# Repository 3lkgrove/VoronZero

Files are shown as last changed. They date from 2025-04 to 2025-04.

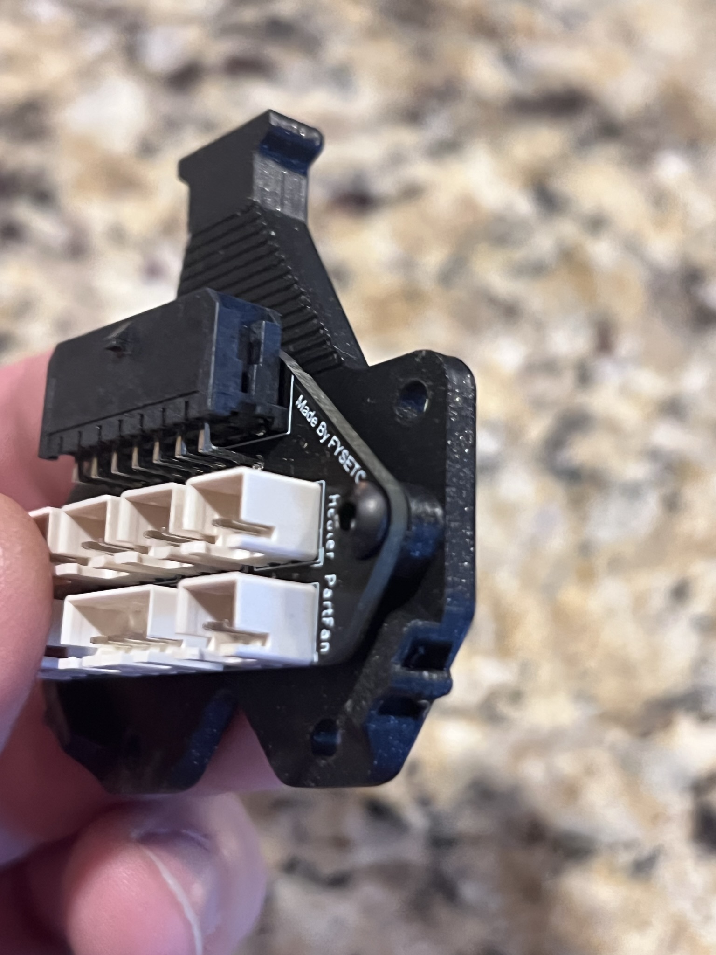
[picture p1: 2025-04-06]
STLs/Umbilical/V0.2/Images/2.JPEG

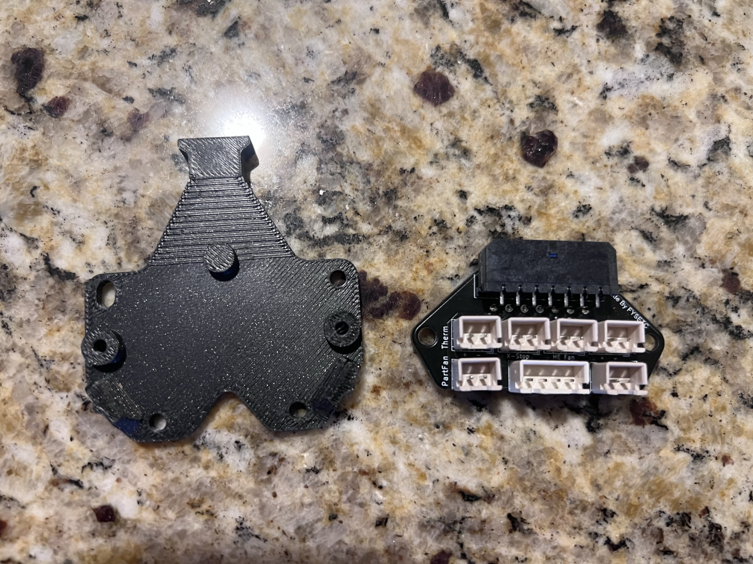
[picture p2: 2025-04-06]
STLs/Umbilical/V0.2/Images/1.JPEG

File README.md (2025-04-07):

# REPO for the Voron 0.2 kit from Formbot 3D

Here you will find some of the additional files, CAD and/or STL, for the components that are included in the Formbot kit of the Voron 0.2. I am also trying to include the manuals as I fidn them. I will also attempt to update a tracker and make some missing/incomplete manauals.

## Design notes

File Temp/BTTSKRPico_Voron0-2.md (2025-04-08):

```RUBY
[include mainsail.cfg]
# This file contains common pin mappings for the BIGTREETECH SKR Pico V1.0
# To use this config, the firmware should be compiled for the RP2040 with
# USB communication.

# The "make flash" command does not work on the SKR Pico V1.0. Instead,
# after running "make", copy the generated "out/klipper.uf2" file
# to the mass storage device in RP2040 boot mode

## Voron Design VORON 0.2 SKR Pico V1.0 config

## *** THINGS TO CHANGE/CHECK: ***
## MCU path                                                                     [mcu] section
## Z and Extruder motor currents                                                [tmc2209 stepper_*] sections. Uncomment the stepper motor you have
## Full steps per rotation for Extruder                                         [extruder] section
## Thermistor types                                                             [extruder] and [heater_bed] sections - See https://www.klipper3d.org/Config_Reference.html#common-thermistors for common thermistor types
## Motor currents                                                               [extruder] [stepper] and [_HOME_X/Y] macro sections
## PID tune                                                                     [extruder] and [heater_bed] sections
## Fine tune E steps                                                            [extruder] section
## For more info                                                                check https://docs.vorondesign.com/build/startup/#v0

[mcu]
#####################################################################
# Obtain definition by "ls -l /dev/serial/by-id/"
#####################################################################
serial: /dev/serial/by-id/usb-Klipper_rp2040_REPLACE_WITH_YOUR_VALUE
## serial: /dev/ttyAMA0 											# for UART connection
restart_method: command

[temperature_sensor mcu_temp]
sensor_type: temperature_mcu
min_temp: 0
max_temp: 100

[temperature_sensor raspberry_pi]
sensor_type: temperature_host
min_temp: 10
max_temp: 100

[printer]
kinematics: corexy
max_velocity: 200
max_accel: 2000
max_z_velocity: 15
max_z_accel: 300
square_corner_velocity: 6.0

#####################################################################
#      X/Y Stepper Settings
#####################################################################

[stepper_x]
step_pin: gpio11
## Refer to https://docs.vorondesign.com/build/startup/#v0
dir_pin: gpio10                                                     # Check motor direction in link above. If inverted, add a ! before gpio10
enable_pin: !gpio12
rotation_distance: 40
microsteps: 32
full_steps_per_rotation: 200                                        # Set to 400 for 0.9° degree stepper motor, 200 is for 1.8° stepper motors
endstop_pin: tmc2209_stepper_x:virtual_endstop
position_endstop: 120
position_max: 120
homing_speed: 40
homing_retract_dist: 0
homing_positive_dir: true

[tmc2209 stepper_x]
uart_pin: gpio9
tx_pin: gpio8
uart_address: 0
interpolate: False
# run_current: 0.0            
# you need to calculate the run_current value using the equation (rated_motor_current * 0.707 = Maximum_run_current) start with a value that is about 60%-70% of your maximum value.
sense_resistor: 0.110
stealthchop_threshold: 0                                            # Set to 999999 to turn stealthchop on, and 0 to use spreadcycle
diag_pin: ^gpio4    												# YOU NEED TO JUMP THIS DIAG PIN ON YOUR BOARD FOR SENSORLESS HOMING TO WORK 
driver_SGTHRS: 255  												# this is set to 255 which is the MAX sensitivity for sensorless homing, you will need to tune this later

[stepper_y]
step_pin: gpio6
## Refer to https://docs.vorondesign.com/build/startup/#v0
dir_pin: gpio5                                                      # Check motor direction in link above. If inverted, add a ! before gpio5
enable_pin: !gpio7
rotation_distance: 40
microsteps: 32
full_steps_per_rotation: 200                                        # Set to 400 for 0.9° degree stepper motor, 200 is for 1.8° stepper motors
endstop_pin: tmc2209_stepper_y:virtual_endstop
position_endstop: 120
position_max: 120
homing_speed: 40
homing_retract_dist: 0
homing_positive_dir: true

[tmc2209 stepper_y]
uart_pin: gpio9
tx_pin: gpio8
uart_address: 2
interpolate: False
# run_current: 0.0            
# you need to calculate the run_current value using the equation (rated_motor_current * 0.707 = Maximum_run_current) start with a value that is about 60%-70% of your maximum value.
sense_resistor: 0.110
stealthchop_threshold: 0                                            # Set to 999999 to turn stealthchop on, and 0 to use spreadcycle
diag_pin: ^gpio3    												# YOU NEED TO JUMP THIS DIAG PIN ON YOUR BOARD FOR SENSORLESS HOMING TO WORK 
driver_SGTHRS: 255  												# this is set to 255 which is the MAX sensitivity for sensorless homing, you will need to tune this later

#####################################################################
#   Z Stepper Settings
#####################################################################

[stepper_z]
step_pin: gpio19
dir_pin: !gpio28                                                    # Remove the ! before gpio28 if motor direction is inverted.
enable_pin: !gpio2
rotation_distance: 8                                                # For T8x8 integrated lead screw
microsteps: 32
endstop_pin: ^gpio25
position_endstop: 120
position_max: 120
position_min: -1.5
homing_speed: 20
second_homing_speed: 3.0
homing_retract_dist: 3.0

[tmc2209 stepper_z]
uart_pin: gpio9
tx_pin: gpio8
uart_address: 1
interpolate: False
## For OMC (StepperOnline) 17LS13-0404E-200G 0.4A 
#run_current: 0.2
## For LDO-42STH25-1004CL200E 1.0A
#run_current: 0.37
sense_resistor: 0.110
stealthchop_threshold: 0                                            # Set to 999999 to turn stealthchop on, and 0 to use spreadcycle

#####################################################################
#   Extruder
#####################################################################

[extruder]
step_pin: gpio14
dir_pin: gpio13                                                     # Add ! if moving opposite direction
enable_pin: !gpio15
#full_steps_per_rotation: 200                                       # Set to 200 for LDO 1.8° stepper motor, and set to 400 for OMC(StepperOnline) 0.9° stepper motor
rotation_distance: 22.23                                            # See calibrating rotation_distance on extruders doc
gear_ratio: 50:10                                                   # For Mini Afterburner
microsteps: 32
nozzle_diameter: 0.400
filament_diameter: 1.750
heater_pin: gpio23
## Check what thermistor type you have. See https://www.klipper3d.org/Config_Reference.html#common-thermistors for common thermistor types.
## Use "Generic 3950" for NTC 100k 3950 thermistors
#sensor_type:
sensor_pin: gpio27
control: pid                                                        # Do PID calibration after initial checks
pid_Kp: 28.182
pid_Ki: 1.978
pid_Kd: 100.397
min_temp: 0
max_temp: 270
min_extrude_temp: 170
max_extrude_only_distance: 150
max_extrude_cross_section: 0.8
pressure_advance: 0.0                                               # See tuning pressure advance doc
pressure_advance_smooth_time: 0.040

[tmc2209 extruder]
uart_pin: gpio9
tx_pin: gpio8
uart_address: 3
interpolate: False
## For OMC (StepperOnline) 14HR07-1004VRN 1A 0.9°
#run_current: 0.5 # for OMC 14HR07-1004VRN rated at 1A
## For LDO LDO 36STH17-1004AHG 1A 1.8° 
#run_current: 0.3 # for LDO 36STH17-1004AHG
## For LDO LDO 36STH20-1004AHG 1A 1.8° 
#run_current: 0.6 # for LDO 36STH20-1004AHG
sense_resistor: 0.110
stealthchop_threshold: 0                                            # Set to 0 for spreadcycle, avoid using stealthchop on extruder

#####################################################################
#   Bed Heater
#####################################################################

[heater_bed]
heater_pin: gpio21
## Check what thermistor type you have. See https://www.klipper3d.org/Config_Reference.html#common-thermistors for common thermistor types.
## Use "Generic 3950" for Keenovo heaters
#sensor_type:
sensor_pin: gpio26
smooth_time: 3.0
#max_power: 0.6                                                     # Only needed for 100w pads
min_temp: 0
max_temp: 120
control: pid                                                        # Do PID calibration after initial checks
pid_kp: 68.453
pid_ki: 2.749
pid_kd: 426.122

#####################################################################
# Fan Control
#####################################################################

[heater_fan hotend_fan]
pin: gpio18
max_power: 1.0
kick_start_time: 0.5
heater: extruder
heater_temp: 50.0
#fan_speed: 1.0                                                     # You can't PWM the delta fan unless using blue wire

[fan]
pin: gpio17
max_power: 1.0
kick_start_time: 0.5                                                # Depending on your fan, you may need to increase this value if your fan will not start
off_below: 0.13
cycle_time: 0.010

[controller_fan MCU_fan]
pin: gpio20
max_power: 1.0
kick_start_time: 0.5
heater: extruder
#fan_speed: 1.0 

#####################################################################
#   Filament Runout Sensor
#####################################################################

#[filament_switch_sensor Filament_Runout_Sensor]
#pause_on_runout: True
#runout_gcode: PAUSE
#switch_pin: gpio16

#####################################################################
# Homing and Gantry Adjustment Routines
#####################################################################

[idle_timeout]
timeout: 1800

#[safe_z_home]
##home_xy_position: 120,120 										# these coordinates must NOT be greater than the values specified in "position_max:" for the X and Y steppers
#speed: 50.0
#z_hop: 5

## To be used with BED_SCREWS_ADJUST
[bed_screws]
screw1: 60,5
screw1_name: front screw
screw2: 5,115
screw2_name: back left
screw3: 115,115
screw3_name: back right

#####################################################################
# Neopixel
#####################################################################

[neopixel board_rgb]
pin: gpio24
chain_count: 1
color_order: GRB
initial_RED: 0.0
initial_GREEN: 0.1
initial_BLUE: 0.0

#####################################################################
#   V0 Display
#####################################################################
# [mcu display]
# serial: **PASTE YOUR SERIAL PORT HERE AND UNCOMMENT**
# restart_method: command

# [display]
# lcd_type: sh1106
# i2c_mcu: display
# i2c_bus: i2c1a
# # Set the direction of the encoder wheel
# #   Standard: Right (clockwise) scrolls down or increases values. Left (counter-clockwise scrolls up or decreases values.
# encoder_pins: ^display:PA3, ^display:PA4
# #   Reversed: Right (clockwise) scrolls up or decreases values. Left (counter-clockwise scrolls down or increases values.
# #encoder_pins: ^display:PA4, ^display:PA3
# click_pin: ^!display:PA1
# kill_pin: ^!display:PA5
# #x_offset: 2
# #   Use X offset to shift the display towards the right. Value can be 0 to 3
# #vcomh: 0
# #   Set the Vcomh value on SSD1306/SH1106 displays. This value is
# #   associated with a "smearing" effect on some OLED displays. The
# #   value may range from 0 to 63. Default is 0.
# #   Adjust this value if you get some vertical stripes on your display. (31 seems to be a good value)

# [neopixel displayStatus]
# pin: display:PA0
# chain_count: 1
# color_order: GRB
# initial_RED: 0.2
# initial_GREEN: 0.05
# initial_BLUE: 0

```

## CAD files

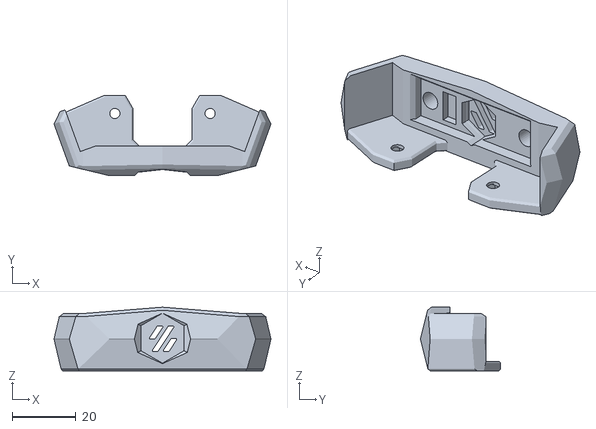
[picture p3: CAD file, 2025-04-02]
STLs/Kirigami/Stealth_Bed_Main_Body.stl
68.2 x 25.2 x 20.0

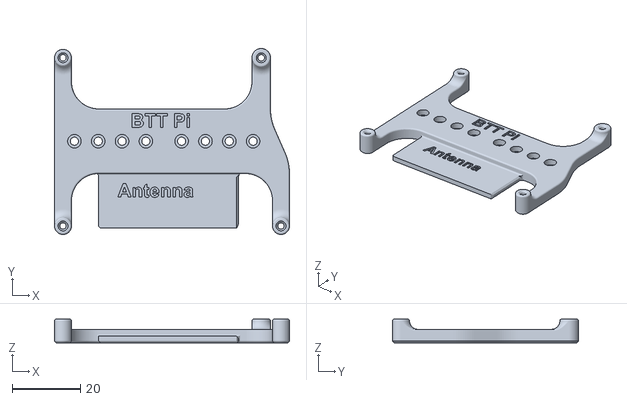
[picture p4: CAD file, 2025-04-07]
STLs/btt_pi_mount_antenna.stl
69.0 x 54.6 x 7.00

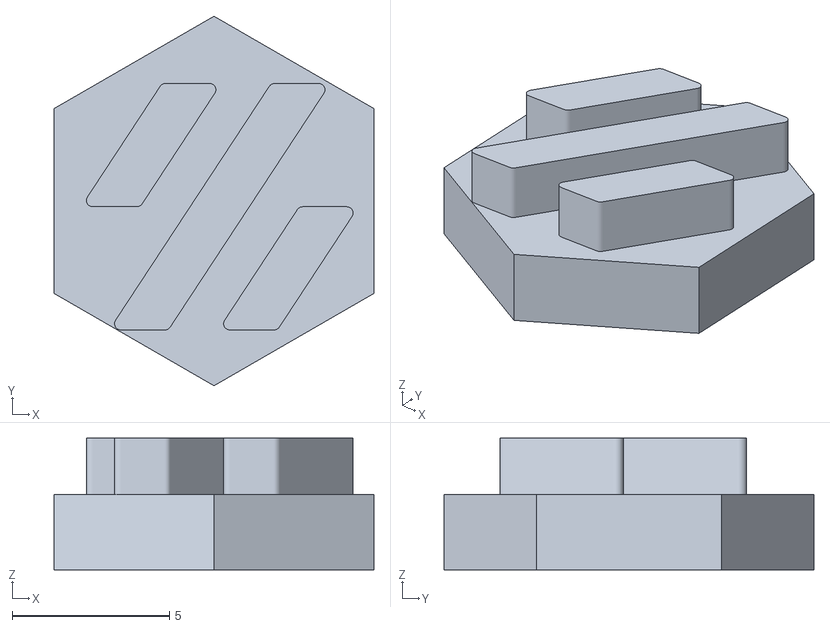
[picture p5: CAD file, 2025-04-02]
STLs/Kirigami/[c]_Stealth_Bed_Diffuser.stl
10.2 x 11.8 x 4.20

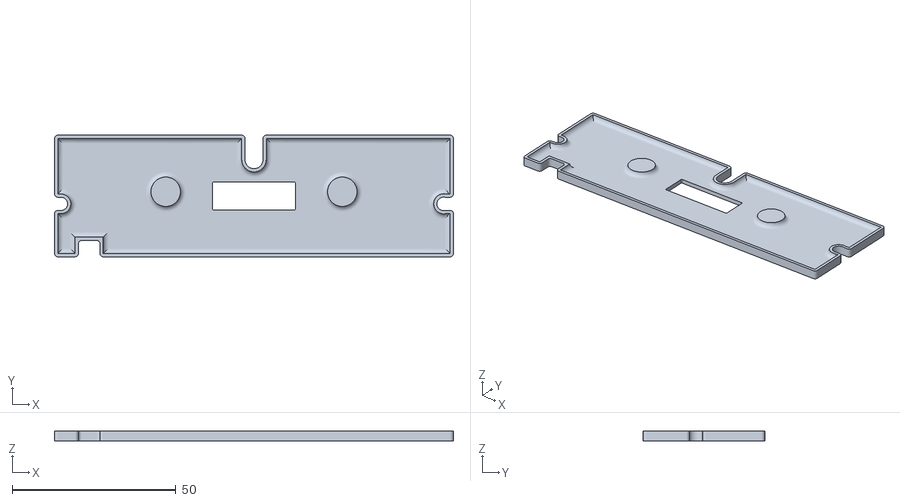
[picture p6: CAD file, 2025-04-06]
STLs/Umbilical/Multicolor PCB Cover/PCB_Cover_Voron.stl
122.0 x 37.2 x 3.00

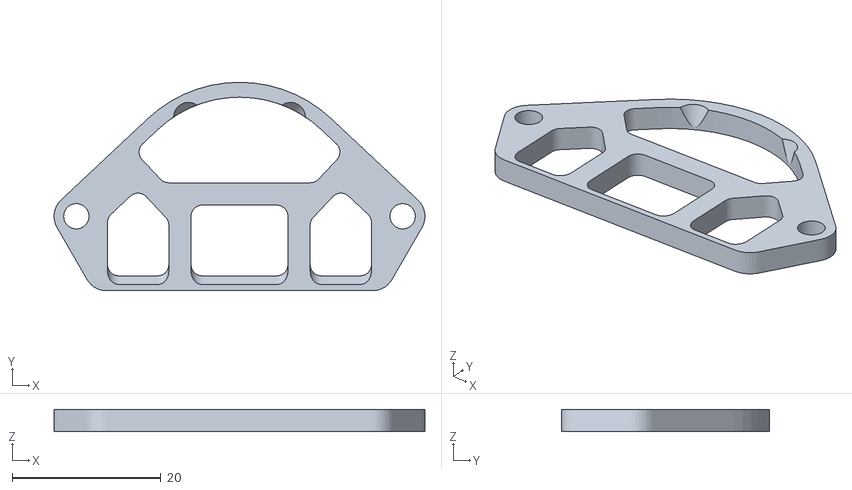
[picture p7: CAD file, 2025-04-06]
STLs/Umbilical/ToolheadSpacer.STL
49.8 x 28.0 x 3.00

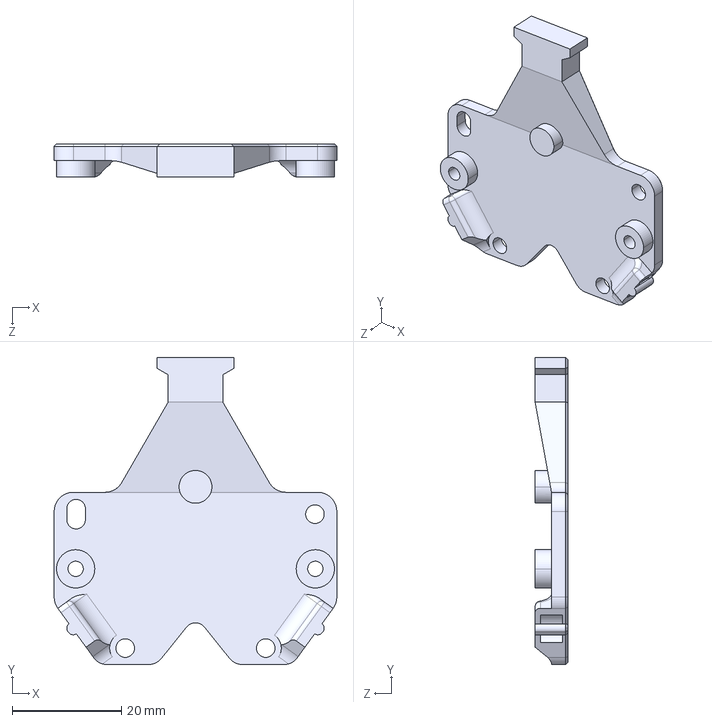
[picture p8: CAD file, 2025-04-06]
STLs/Umbilical/V0.2/V0.2_Toolhead_PCB_Mount.STEP
51.7 x 56.2 x 6.00 mm

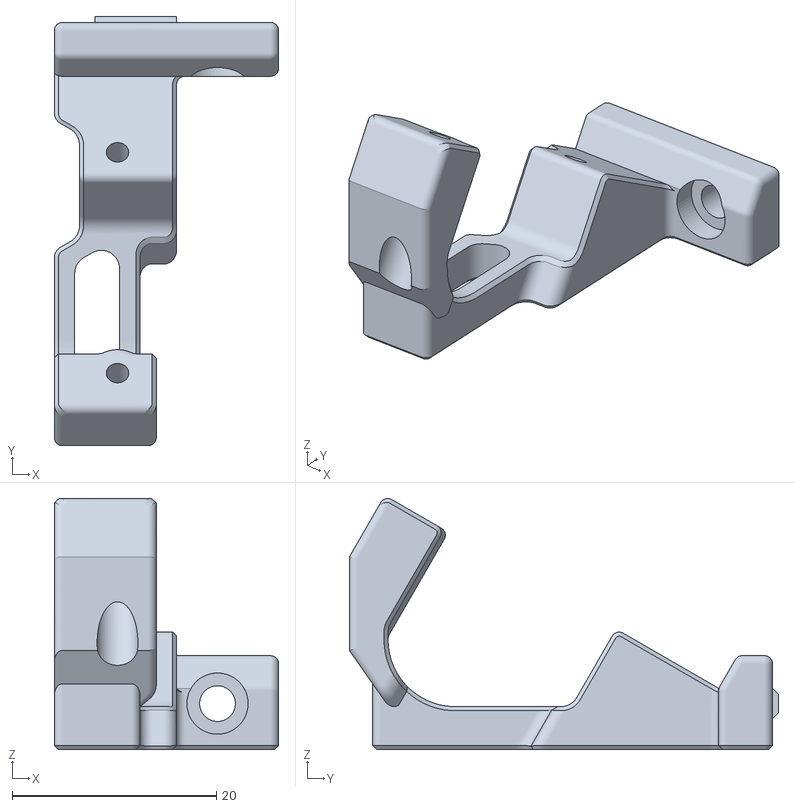
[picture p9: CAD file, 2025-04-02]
STLs/V0/Display/Display_Mount_Left_x1.stl
22.0 x 42.1 x 24.6

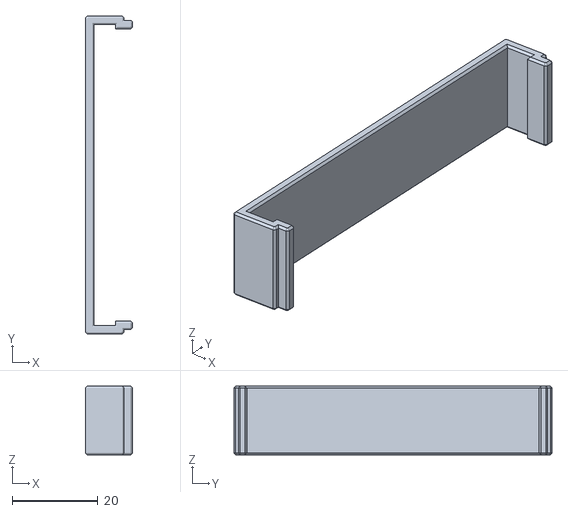
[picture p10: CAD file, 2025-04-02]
STLs/V0/Electronics/PSU_Cover_x1.STL
11.0 x 74.2 x 16.0

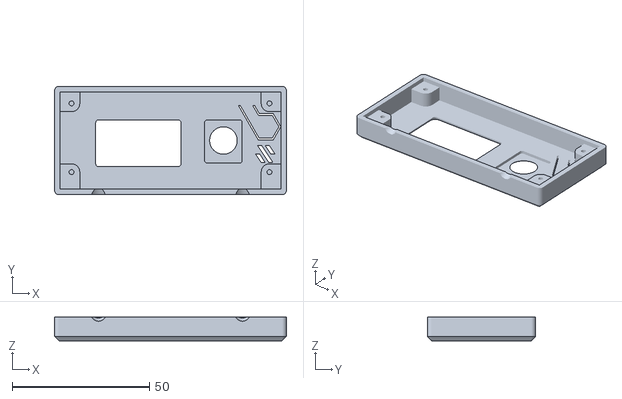
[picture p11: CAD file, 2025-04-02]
STLs/V0/Multibody_STLs/Display/Display_Faceplate_Multibody_x1.stl
84.4 x 39.4 x 8.63

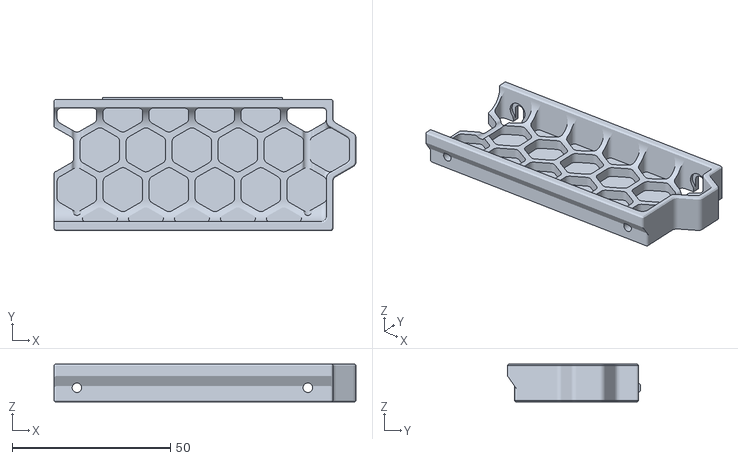
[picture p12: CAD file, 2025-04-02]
STLs/V0/Multibody_STLs/Skirts/Side_Skirt_Mirror_Multibody_x2.stl
95.5 x 42.1 x 12.0

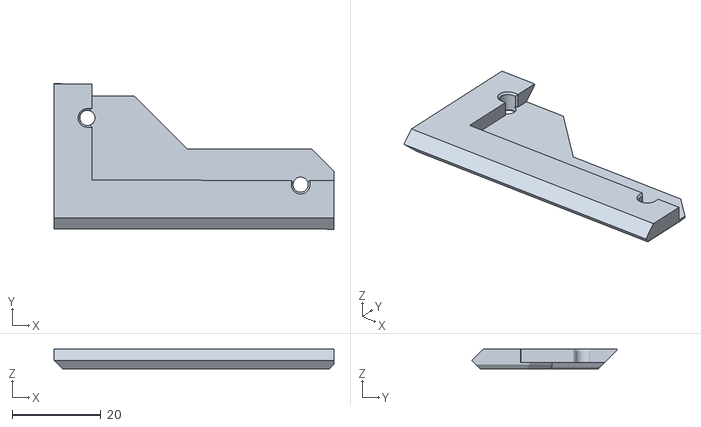
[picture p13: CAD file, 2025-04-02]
STLs/V0/Panel_Mounting/Right_Top_Rear_Panel_Clip_x1.stl
63.0 x 32.7 x 4.40

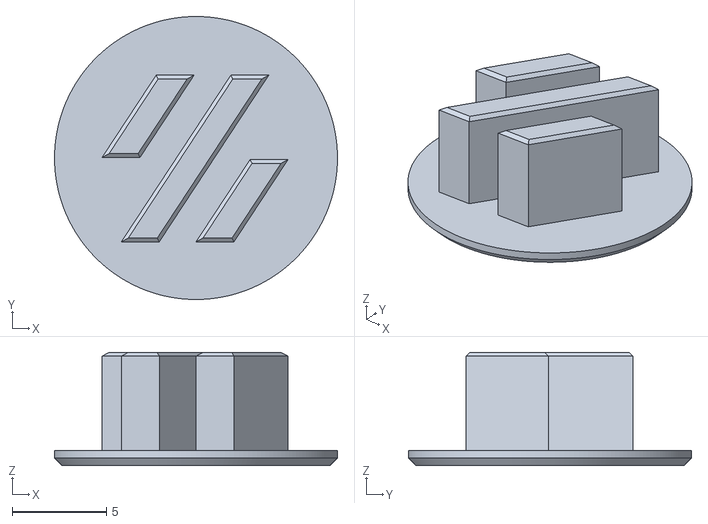
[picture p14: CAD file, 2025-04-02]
STLs/V0/Skirts/[a]_Logo_Insert_x2.stl
15.0 x 15.0 x 6.00

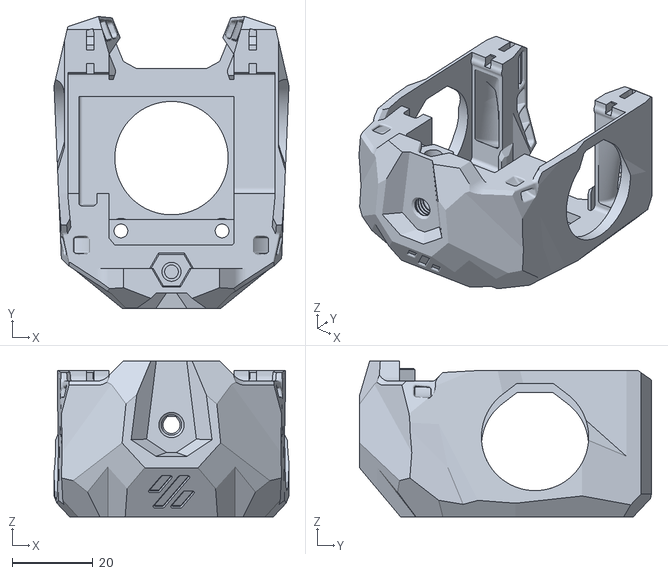
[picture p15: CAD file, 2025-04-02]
STLs/V0/Toolheads/Bowden/MiniSB_Bowden_M6.STL
58.1 x 72.2 x 38.5

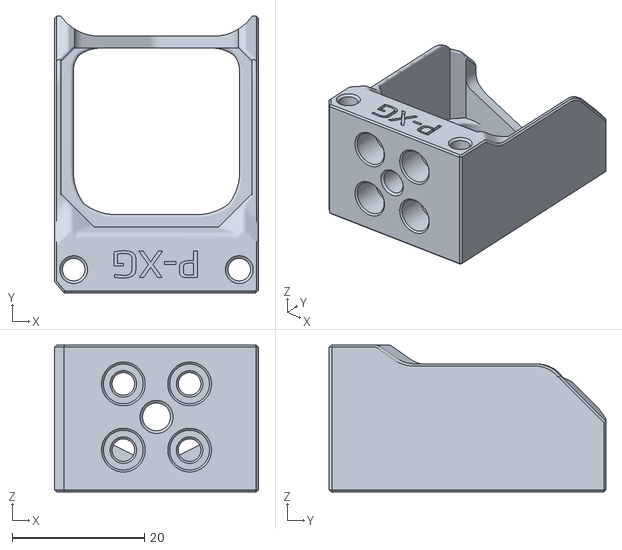
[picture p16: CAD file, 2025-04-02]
STLs/V0/Toolheads/Hotend_Mounts/Fan_Saver/[a]_FS_Hotend_Mount_Drop_Effect_XG.stl
30.8 x 41.8 x 22.2

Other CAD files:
STLs/V0/Toolheads/Hotend_Mounts/Standard/[a]_Hotend_Mount_Revo_Voron.stl
STLs/V0/Toolheads/Mini_Stealthburner/[a]_MiniSB_Motor_Plate_x1.stl
STLs/V0/Tools/V0_Extrusion_Drilling_Guide_x1.STL
STLs/V0/Tophat/TH_Lower_Clip_Mirror_x3.stl
STLs/Kirigami/VORON v0.0_v0.1_legacy_chain_mount.stl
STLs/Kirigami/VORON_v0.0-v0.1_stealth_nut_block.stl
STLs/Kirigami/VORON_v0.2_belt_chain_mount.stl
STLs/Kirigami/VORON_v0.2_stealth_chain_mount.stl
STLs/Kirigami/VORON_v0.2_stealth_chain_mount_5mm_spacer.stl
STLs/Kirigami/VORON_v0.2_stealth_nut_block.stl
STLs/Kirigami/VORON_v0.2_stealth_wire_guide.stl
STLs/Kirigami/kirigami_wago_mount.stl
STLs/Umbilical/FramePCBCover.STL
STLs/Umbilical/Multicolor PCB Cover/PCB_Cover.step
STLs/Umbilical/Multicolor PCB Cover/PCB_Multicolor.3mf
STLs/Umbilical/Multicolor PCB Cover/PCB_Text.stl
STLs/Umbilical/PTFE_Guide.stl
STLs/Umbilical/ToolheadSpacer_with_StrainRelief.STL
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

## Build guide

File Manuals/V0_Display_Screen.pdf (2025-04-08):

# V0 Display Screen

V0 Display Flickering Instructions

Connection
The display is connected to the host computer via USB. Firmware Pre-Installation Check
Determine if your display has firmware pre-installed: If the display has pre-flashed firmware:
Install a jumper cap in the red area shown in the image below and press the RSSCT button to put the development board into DFU mode.

If the display does not have firmware pre-flashed:
The MCU defaults to DFU mode if no other firmware is installed. Confirm that the development board enters DFU mode in step 4. Connect via SSH
Connect to your host computer using SSH. Verify DFU Mode
Run the command:

Ensure the STM32 is listed in DFU mode.

lsusb

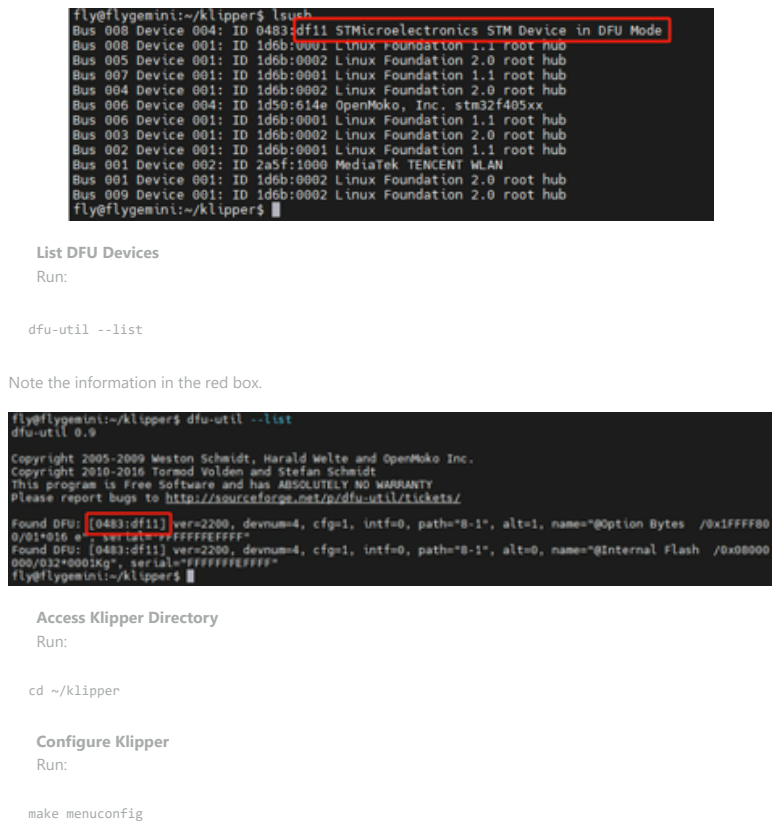
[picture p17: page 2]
Configure Klipper Run:; cd ~/klipper; make menuconfig

List DFU Devices
Run:

dfu-util --list

Note the information in the red box.

Access Klipper Directory

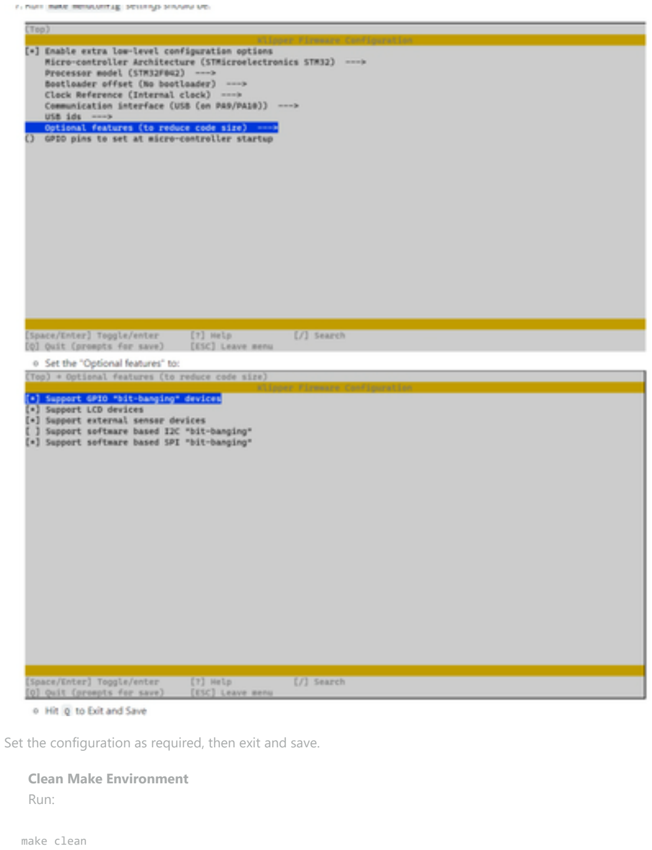
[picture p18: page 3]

Set the configuration as required, then exit and save.

Clean Make Environment
Run:

make clean

Flash Firmware
Run:

(Use the appropriate xxxx:yyyy from the previous step.)

Final Steps

Remove the power jumper.
Press the reset button.

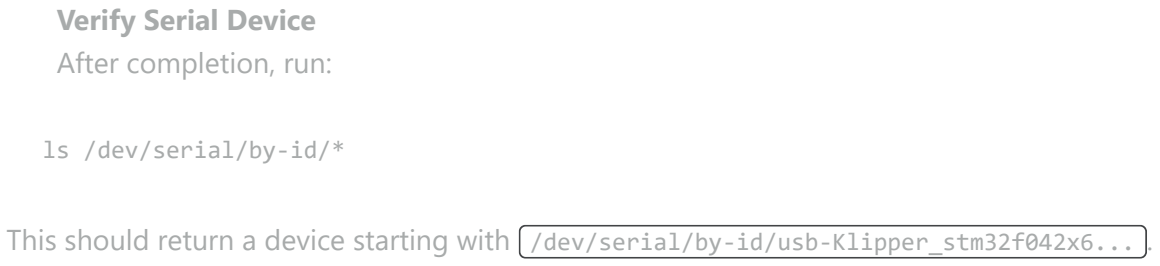
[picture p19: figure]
Verify Serial Device After completion, run:; ls /dev/serial/by-id/*

This should return a device starting with /dev/serial/by-id/usb-Klipper_stm32f042x6... .

Update Display Configuration
Copy the serial port name (e.g., /dev/serial/by-id/usb-Klipper_stm32f042x6... ) and place it in the
[mcu display] section of the display configuration file.

make flash FLASH_DEVICE=0483:df11

### Example Configuration for V0Display.cfg

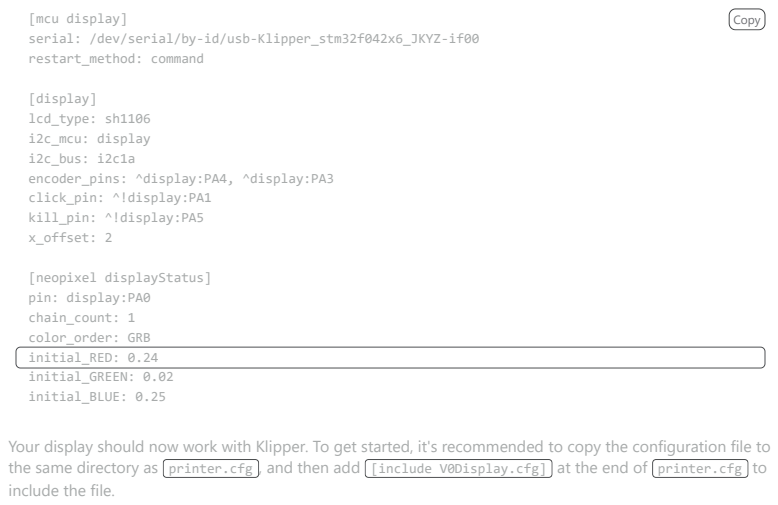
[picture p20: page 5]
[display] lcd_type: sh1106 i2c_mcu: display i2c_bus: i2c1a encoder_pins: ^display:PA4, ^display:PA3 click_pin: ^!display:PA1 kill_pin: ^!display:PA5 x_offset: 2; [neopixel displayStatus] pin: display:PA0 chain_count: 1 color_order: GRB; initial_GREEN: 0.02 initial_BLUE: 0.25; initial_RED: 0.24; Copy

[mcu display]
serial: /dev/serial/by-id/usb-Klipper_stm32f042x6_JKYZ-if00
restart_method: command

Your display should now work with Klipper. To get started, it's recommended to copy the configuration file to
the same directory as printer.cfg , and then add [include V0Display.cfg] at the end of printer.cfg to
include the file.

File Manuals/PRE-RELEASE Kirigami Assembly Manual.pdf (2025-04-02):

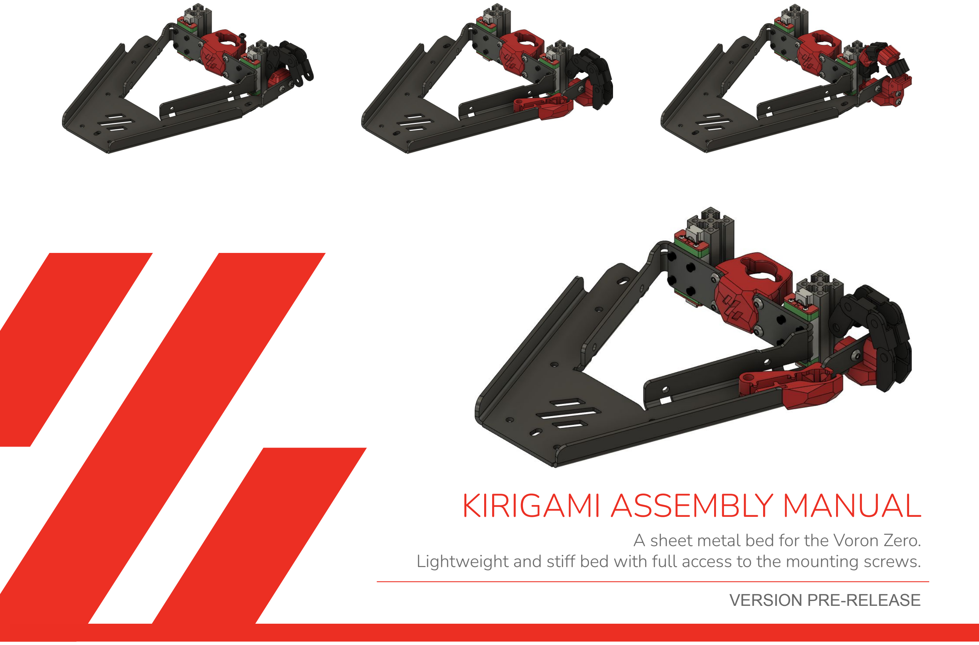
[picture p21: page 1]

# KIRIGAMI ASSEMBLY MANUAL

A sheet metal bed for the Voron Zero. Lightweight and stiff bed with full access to the mounting screws.

VERSION PRE-RELEASE

TABLE OF CONTENTS | https://github.com/christophmuellerorg/voron_0_kirigami_bed

2

Introduction | 3
Check your bed | 5
Hardware reference | 6
To BOM or not to BOM | 7
Printed parts reference | 8
Printed parts reference (optional/mods) | 12

### How this manual was made

2

REMEMBER TO MAKE THESE CLICKABLE LINKS, BOTH TEXT AND NUMBERS

INTRODUCTION | https://github.com/christophmuellerorg/voron_0_kirigami_bed

3

KIRIGAMI BED
The Kirigami bed is a stiff and lightweight, bent, single piece metal bed upgrade for the Voron 0 series. It replaces the entire bed carrier from the original Voron V0 design, i.e. everything between the Z-axis rail carriages and the heated bed.

3

INTRODUCTION | https://github.com/christophmuellerorg/voron_0_kirigami_bed

4

HOW TO USE THIS MANUAL
This manual is a complement to the official Voron Zero assembly manual. You can consider it a replacement for parts of the manual.

V0.2R1 manual (2023-06-07 version)
This manual complements/replaces pages 36-47.
Remember to use the correct printed nut holder on pages 92-93.

V0.2 manual (2023-03-03 version)
This manual complements/replaces pages 36-46.
Remember to use the correct printed nut holder on pages 92-93.

V0.1 manual
This manual complements/replaces pages 13, 19-20, and 27-30. Remember to use the correct printed nut holder on pages 59-60..

V0.0 manual
This manual complements/replaces pages 12-20.
Remember to use the correct printed nut holder on pages 27 and 32.

4

LDO PRINTER KIT OR LDO KIRIGAMI KIT
Please be aware that LDO also have their own guide from a Kirigami bed on a V0.1 (https://www.ldomotion.com/p/guide/Kirigami-Bed-for-Voron-V01) and for the V0.2/v0.2R1 (https://www.ldomotion.com/p/guide/Kirigami-Bed-for-Voron-V02. )

These guides should be enough if you are building based on a LDO kit, but this guide includes the same information.

The LDO Kirigami V0.2/V0.2R1 guide is using graphics from this guide with permission.

CHECK YOUR BED | https://github.com/christophmuellerorg/voron_0_kirigami_bed

METAL BUT BENDABLE
The Kirigami bed is a metal, most commonly aluminum, but also available in steel, folded sheet bed. It may still be bent out of spec during production, transport or mounting. You should check the measurements, parallelism and coplanarity (flat in respect to each other) of you metal bed before starting your assembly.

20 mm

2 mm

CHECK BED MOUNT FLATNESS
These two surfaces MUST be coplanar (https://www.tec-ease.com/gdt-tips-view.php?q=143) (flat in respect to each other) to prevent binding of the Z rails.

NUT BLOCK
The spec on the metal
frame is 2 mm thickness
and a 20 mm gap where
the nut block attaches to
the frame. The nut block
is designed with a
absolute maximum of 2.2
mm thickness, and a
absolute minimum gap of
19.5 mm.
⊘

⊘

HARDWARE REFERENCE | https://github.com/christophmuellerorg/voron_0_kirigami_bed

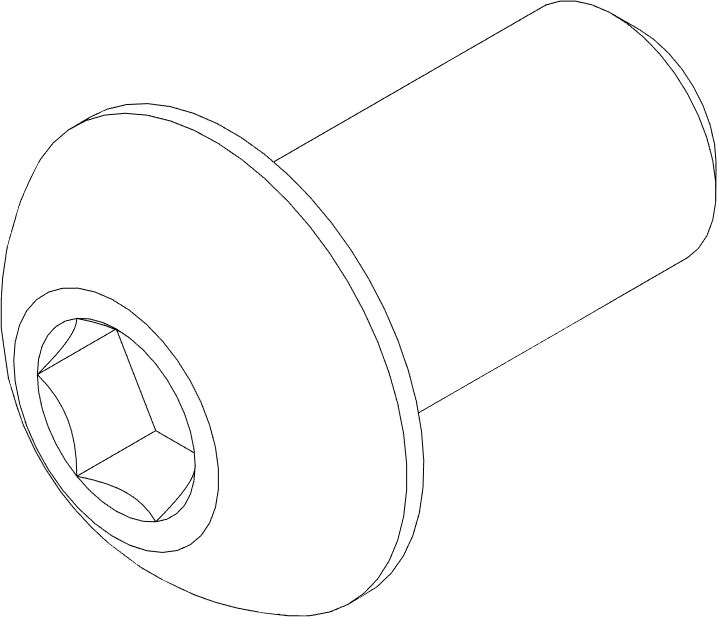
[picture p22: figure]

BUTTON HEAD CAP SCREW (BHCS) Metric fastener with a domed shaped head and hex drive.

ISO 7380-1

HEX NUT
Hex nuts couple with bolts to create a tight, secure joint. Used in some optional parts instead of heat set inserts.

ISO 4032 / DIN 934

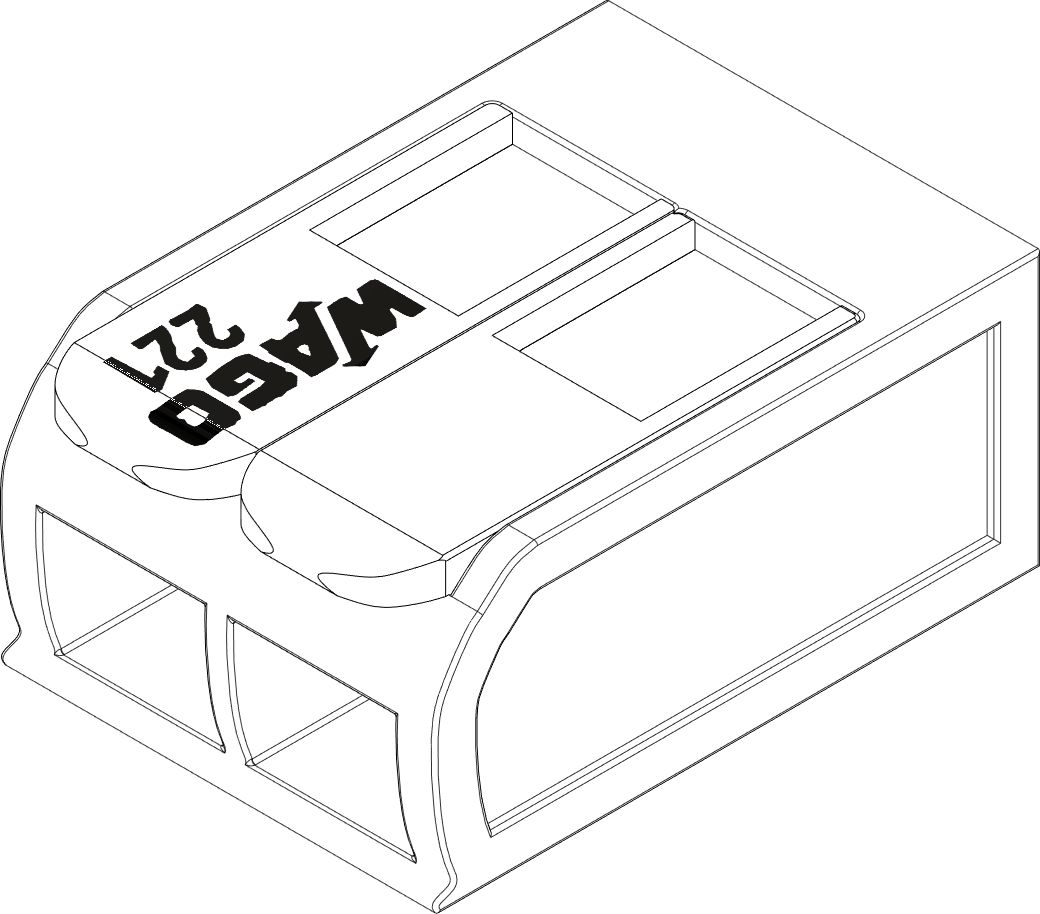
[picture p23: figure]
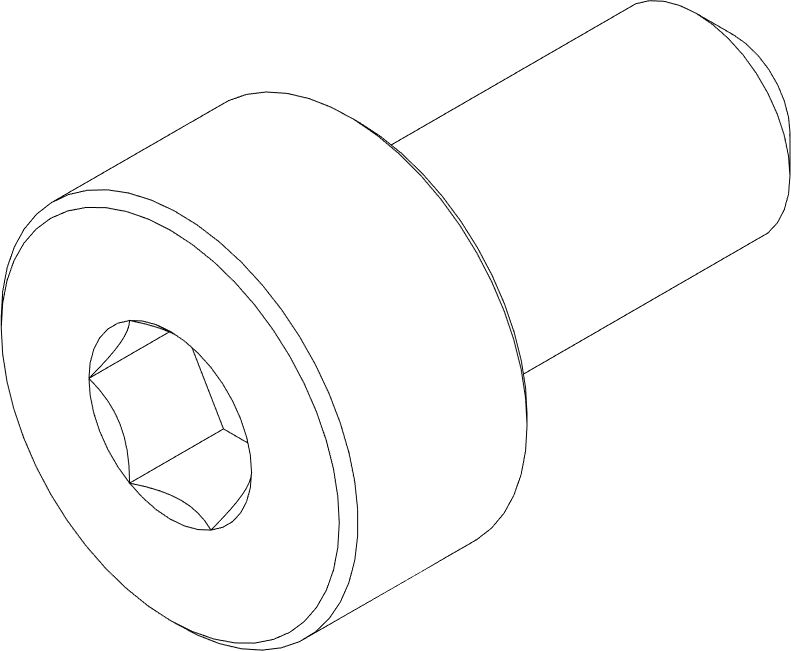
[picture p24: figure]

SOCKET HEAD CAP SCREW (SHCS) Metric fastener with a cylindrical head and hex drive.

ISO 4762 / DIN 912

SPLICING CONNECTOR
A WAGO splicing connector is a tool-free, lever-actuated connector used in some optional parts for splicing bed power wiring.

WAGO 221-412

HEAT SET INSERT
A heat set insert heated by a soldering iron allows you to install metal threads into plastic parts.

Voron designs commonly use heat set inserts with M3 internal threads, a 5mm outer diameter and a height of 4mm.

BOM | https://github.com/christophmuellerorg/voron_0_kirigami_bed

BILL OF MATERIALS
Here we could have had a BOM.

With all the V0 versions and optional parts this guide describes, we figured it would be better if you read through the following pages and sum up the totals yourself.

Printed parts will have a list of parts required to mount and use them.

You will need 8x M2x4 (preferably SHCS) screws to mount the metal bed to the carriages. Be aware that the default V0 extrusion bed uses M2x8, not x4.

If screw type (BHCS, SHCS) is not mentioned in this guide, assume BHCS is recommended.

PRINTED PARTS | https://github.com/christophmuellerorg/voron_0_kirigami_bed

PRINTED PARTS (REQUIRED)
Depending on where you got your Kirigami bed, what accessories it included, what version of a Voron V0 you are building, and depending on what kind of cable chain you are using, the printed parts you will need differ.

Use the same recommended settings as in the official manual. The positions the parts have in the STL files are the recommended printing positions. Supports should not be required.

The next four pages will list four possible combinations of parts you will need to get a functional bed.

In the top middle of the pages you will see if this options is for a V0.0/V0.1 or V0.2/V0.2R1, and if it is for a IGUS or Generic Chinese chain, or for a belt chain.

STEALTH EVERYTHING!!!
When looking at printed parts you may notice the word stealth in many names. This is simply to indicate it is of the stealth design style, made popular by the Voron Stealthburner toolhead design.

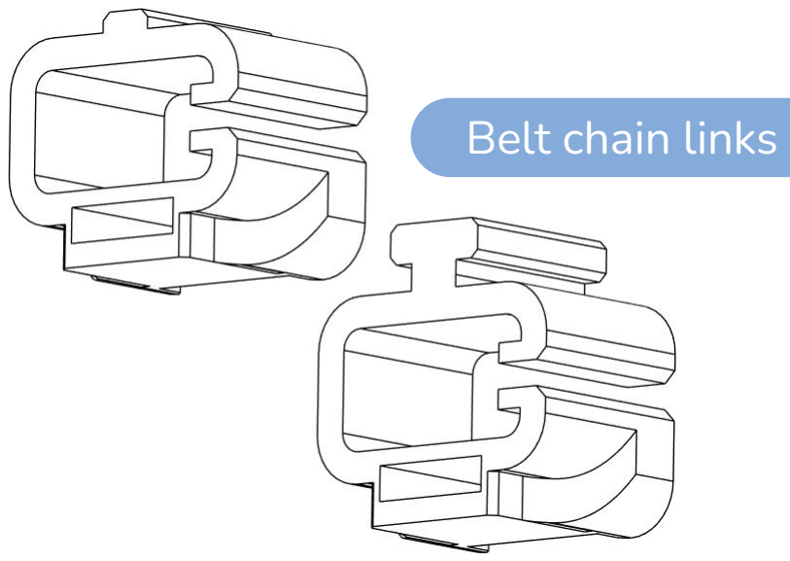
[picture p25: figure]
Belt chain links

The V0 beltchains mod by Iakabos is a alternative cable chain for the Z axis of V0 printer. Instead of using a mass produced standard chain, it is made up uf several printed links that are held together by a GT2 belt, as used in the V0 motion system.

A belt chain is a advanced mod, and not recommended for beginners. If you are using a belt chain, it is assumed you know how to build it. It is not explained further in this manual.

https://mods.vorondesign.com/detail/F5KwWIj cSXwIeghsMo3A (https://mods.vorondesign.com/detail/F5KwWIjcSXwIeghsMo3A)

IGUS is a common supplier of cable chains, with multiple generic versions available from chinese suppliers. This is the most common type of cable chain on V0 printers.

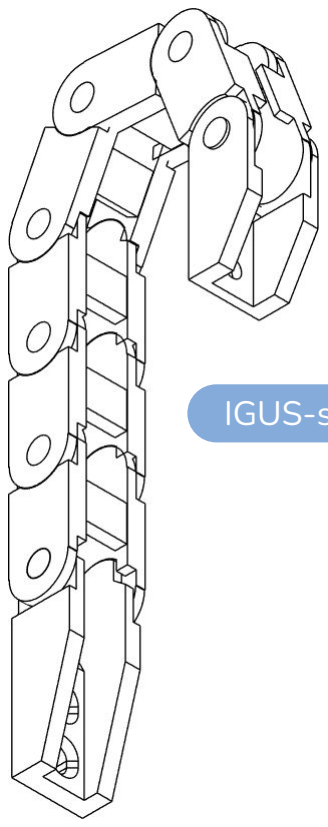
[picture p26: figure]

### IGUS-style chain

PRINTED PARTS REFERENCE (REQUIRED, OPTION 1/4) | https://github.com/christophmuellerorg/voron_0_kirigami_bed

WHAT VERSION OF VORON V0 ARE YOU BUILDING? This page lists the parts for building a Voron V0.2/V0.2R1 with a IGUS or Generic Chinese chain.

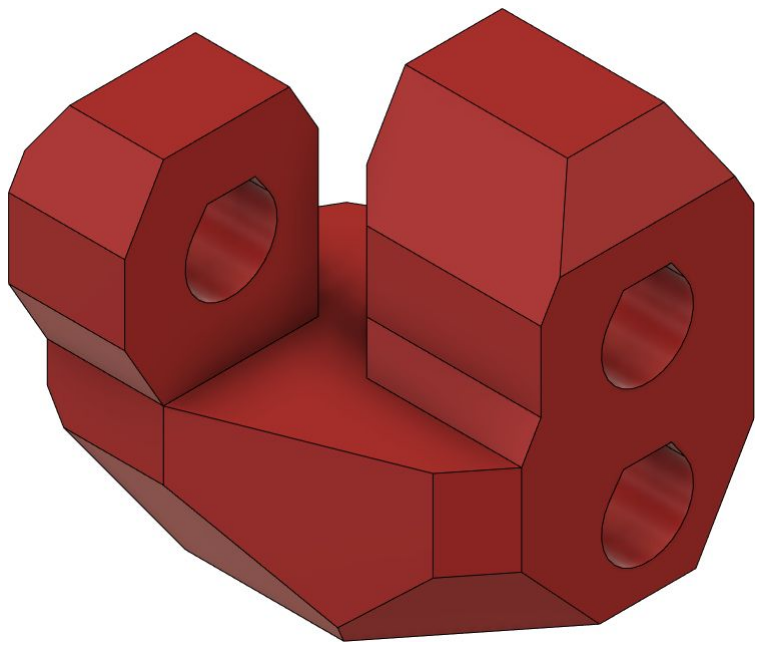
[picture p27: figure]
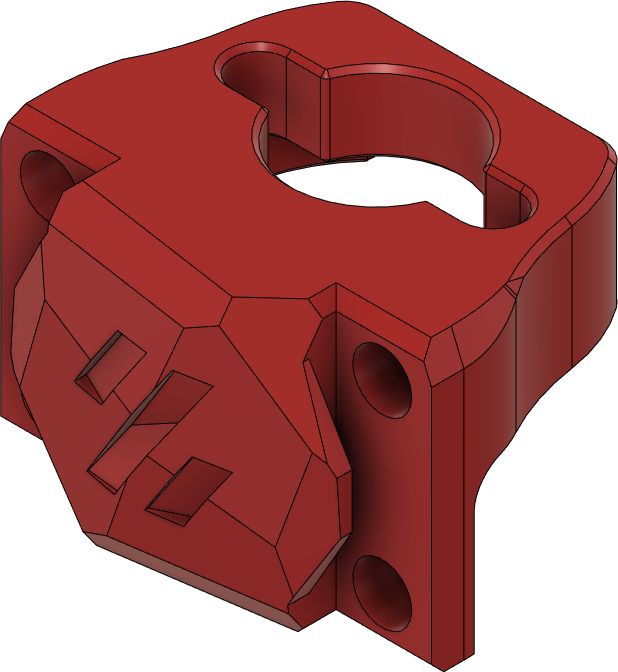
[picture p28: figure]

CHAIN MOUNT BLOCK
Chain mounting block. Sits between the Kirigami metal frame and chain.
3x M3 heat set inserts, 3x M3x6 screws.

VORON_v0.2_stealth_chain_mount.stl (https://github.com/christophmuellerorg/voron_0_kirigami_bed/blob/master/STL/VORON_v0.2_stealth_chain_mount.stl)

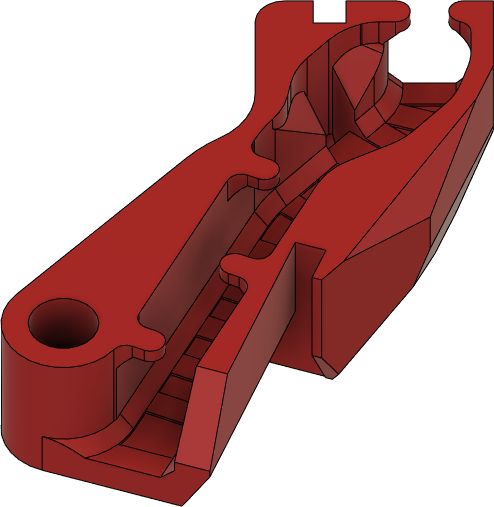
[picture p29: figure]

WIRE GUIDE
Wire guide to feed the cables from the outside to the inner Kirigami channel. 1x M3 heat set inserts,1x M3x6 screw.

VORON_v0.2_stealth_wire_guide.stl (https://github.com/christophmuellerorg/voron_0_kirigami_bed/blob/master/STL/VORON_v0.2_stealth_wire_guide.stl)

NUT BLOCK
This is the nut block that connects the Kirigami frame to the anti-backlash nut and thus to the Z lead screw.
4x M3 heat set inserts, 4x M3x6 screws.

VORON_v0.2_stealth_nut_block.stl (https://github.com/christophmuellerorg/voron_0_kirigami_bed/blob/master/STL/VORON_v0.2_stealth_nut_block.stl)

(OPTIONAL) CHAIN MOUNT SPACER
This is a optional spacer between the chain mount block and chain for some Chinese chains that has a wider bend radius than more common chains.

VORON_v0.2_stealth_chain_mount_5mm_spacer.stl (https://github.com/christophmuellerorg/voron_0_kirigami_bed/blob/master/STL/VORON_v0.2_stealth_chain_mount_5mm_spacer.stl)

PRINTED PARTS REFERENCE (REQUIRED, OPTION 2/4) | https://github.com/christophmuellerorg/voron_0_kirigami_bed

WHAT VERSION OF VORON V0 ARE YOU BUILDING? This page lists the parts for building a Voron V0.2/V0.2R1 with a belt chain.

CHAIN MOUNT BLOCK
Chain mounting block. Sits between the Kirigami metal frame and chain.
3x M3 heat set inserts, 3x M3x6 screws.

VORON_v0.2_stealth_chain_mount.stl (https://github.com/christophmuellerorg/voron_0_kirigami_bed/blob/master/STL/VORON_v0.2_stealth_chain_mount.stl)

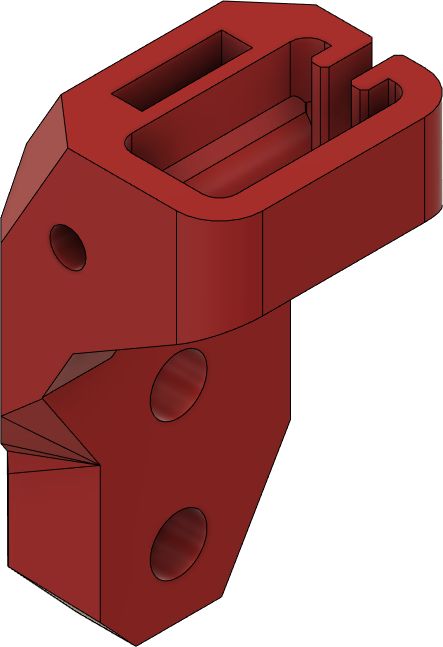
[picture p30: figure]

WIRE GUIDE
Wire guide to feed the cables from the outside to the inner Kirigami channel. 1x M3 heat set inserts, 1x M3x6 screw.

VORON_v0.2_stealth_wire_guide.stl (https://github.com/christophmuellerorg/voron_0_kirigami_bed/blob/master/STL/VORON_v0.2_stealth_wire_guide.stl)

NUT BLOCK
This is the nut block that connects the Kirigami frame to the anti-backlash nut and thus to the Z lead screw.
4x M3 heat set inserts, 4x M3x6 screws.

VORON_v0.2_stealth_nut_block.stl (https://github.com/christophmuellerorg/voron_0_kirigami_bed/blob/master/STL/VORON_v0.2_stealth_nut_block.stl)

BELT CHAIN MOUNT
Bottom mounting block to adapt the belt chain to the chain mounting block. If you are using a belt chain, it is assumed you know how to build it. It is not explained further in this manual.

VORON_v0.2_belt_chain_mount.stl (https://github.com/christophmuellerorg/voron_0_kirigami_bed/blob/master/STL/VORON_v0.2_belt_chain_mount.stl)

PRINTED PARTS REFERENCE (REQUIRED, OPTION 3/4) | https://github.com/christophmuellerorg/voron_0_kirigami_bed

WHAT VERSION OF VORON V0 ARE YOU BUILDING? This page lists the parts for building a Voron V0.0 or 0.1 with a IGUS or Generic Chinese chain.

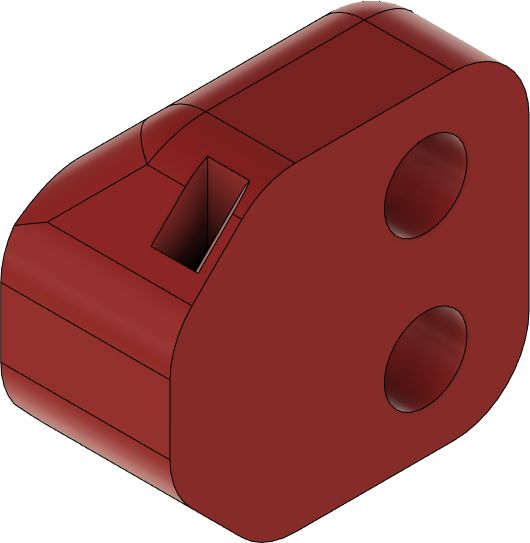
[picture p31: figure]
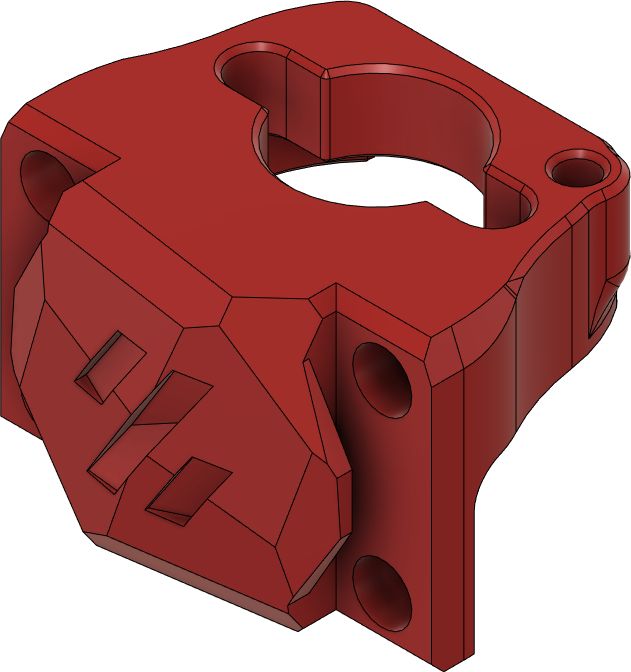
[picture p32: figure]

LEGACY CHAIN MOUNT BLOCK
Chain mount block for IGUS or Generic Chinese chain.
4x M3 heat set inserts, 4x M3x6 screws.

VORON v0.0_v0.1_legacy_chain_mount.stl (https://github.com/christophmuellerorg/voron_0_kirigami_bed/blob/master/STL/VORON%20v0.0_v0.1_legacy_chain_mount.stl)

NUT BLOCK
This is the nut block that connects the Kirigami frame to the anti-backlash nut and thus to the Z lead screw.
4x M3 heat set inserts, 4x M3x6 screws. Notice the top screw hole for Z endstop adjustment screw.

VORON_v0.0-v0.1_stealth_nut_block.stl (https://github.com/christophmuellerorg/voron_0_kirigami_bed/blob/master/STL/VORON_v0.0-v0.1_stealth_nut_block.stl)

PRINTED PARTS REFERENCE (REQUIRED, OPTION 4/4) | https://github.com/christophmuellerorg/voron_0_kirigami_bed

WHAT VERSION OF VORON V0 ARE YOU BUILDING? This page lists the parts for building a Voron V0.0 or 0.1 with a a belt chain.

NUT BLOCK
This is the nut block that connects the Kirigami frame to the anti-backlash nut and thus to the Z lead screw.
4x M3 heat set inserts, 4x M3x6 screws. Notice the top screw hole for Z endstop adjustment screw.

VORON_v0.0-v0.1_stealth_nut_block.stl (https://github.com/christophmuellerorg/voron_0_kirigami_bed/blob/master/STL/VORON_v0.0-v0.1_stealth_nut_block.stl)

WIRE GUIDE
Wire guide to feed the cables from the outside belt chain to the inner Kirigami channel.
1x M3 heat set inserts, 1x M3x6 screw.

VORON_v0.2_stealth_wire_guide.stl (https://github.com/christophmuellerorg/voron_0_kirigami_bed/blob/master/STL/VORON_v0.2_stealth_wire_guide.stl)

CHAIN MOUNT BLOCK
Chain mounting block. Sits between the Kirigami metal frame and chain.
3x M3 heat set inserts, 3x M3x6 screws.

VORON_v0.2_stealth_chain_mount.stl (https://github.com/christophmuellerorg/voron_0_kirigami_bed/blob/master/STL/VORON_v0.2_stealth_chain_mount.stl)

BELT CHAIN MOUNT
Bottom mounting block to adapt the belt chain to the chain mounting block. If you are using a belt chain, it is assumed you know how to build it. It is not explained further in this manual.

VORON_v0.2_belt_chain_mount.stl (https://github.com/christophmuellerorg/voron_0_kirigami_bed/blob/master/STL/VORON_v0.2_belt_chain_mount.stl)

PRINTED PARTS | https://github.com/christophmuellerorg/voron_0_kirigami_bed

PRINTED PARTS (OPTIONAL/MODS)
The following three pages list optional parts you may want for your bed.

If you have a Kirigami bed as part of a LDO kit, you will probably need both the LDO Wago Mount and the LDO Stealth Bed Front.

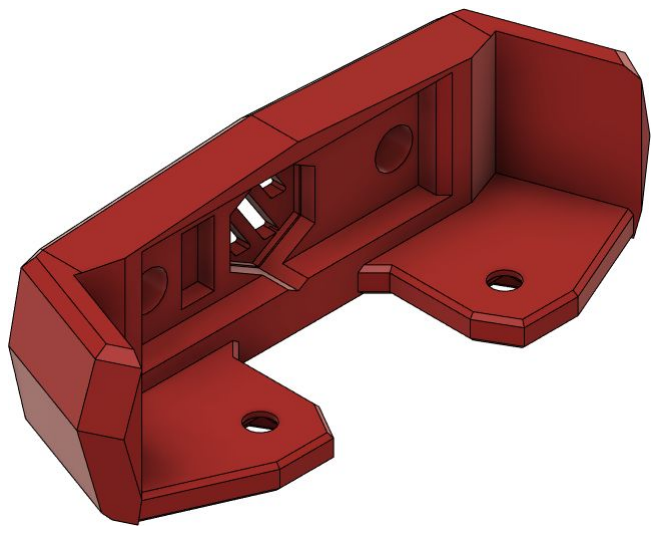
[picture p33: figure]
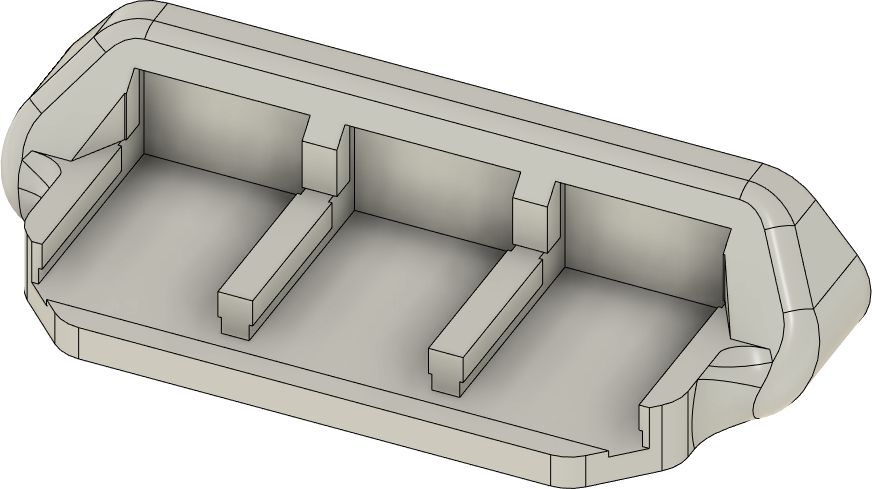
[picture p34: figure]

PRINTED PARTS REFERENCE (OPTIONAL/MODS) | https://github.com/christophmuellerorg/voron_0_kirigami_bed

OPTIONAL PARTS / MODS
These parts are not required for a functional bed, but improve the use or look of the bed. These two parts are LDO specific, and require PCBs from a LDO kit for proper use.

LDO STEALTH BED FRONT
This is the LDO remix of the Maple Leaf Makers Stealth Bed Front (see the next page for the original). It is a visual part that mounts to the front of your bed, and come with a Neopixel-style PCB you can mount inside the front print.

You can either buy a full LDO Kirigami kit, or just the wiring and PCBs.

2x M3 heat set inserts, 4x M3x6 screw, 2 M3 hex nuts, Neopixel PCB from LDO kit.

The diffuser should be printed in a clear (transparent) filament, but is rendered opaque on this page for better visuals. The bed front should be printed in your accent color.

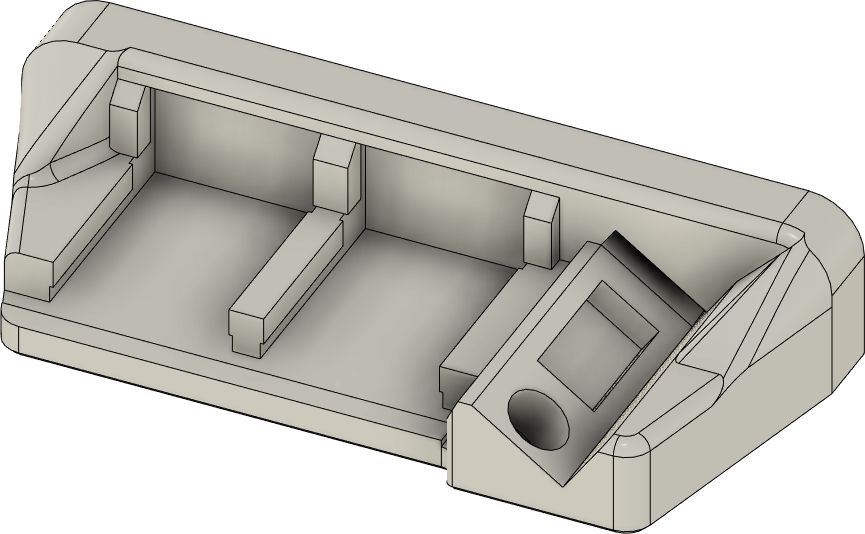
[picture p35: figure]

LDO Kirigami STLs (https://github.com/MotorDynamicsLab/LDOVoron0/tree/main/STLs/Kirigami)

### Diffuser (rear / front)

LDO WAGO MOUNT
This mount allows you to mount two WAGO splicing connectors and the accompanying “Joiner PCB” that is part of the LDO Kirigami kit.
3x M3 heat set inserts, 3x M3x6 screw. Joiner PCB from LDO kit.

You probably want to print this part in your primary color. It is rendered grey/white on this page for better visuals.

Kirigami_LDO_Breakout_Mount.stl (https://github.com/MotorDynamicsLab/LDOVoron0/blob/main/STLs/Kirigami/Kirigami_LDO_Breakout_Mount.stl)

PRINTED PARTS REFERENCE (OPTIONAL/MODS) | https://github.com/christophmuellerorg/voron_0_kirigami_bed

OPTIONAL PARTS / MODS
These parts are not required for a functional bed, but improve the use or look of the bed.

MAPLE LEAF MAKERS STEALTH BED FRONT
This is the Maple Leaf Makers Stealth Bed Front. It is a generic front for small printers that is compatible with the Kirigami. It is a visual part that mounts to the front of your bed and supports either the Rainbow Barf Logo LED (RBL) (https://github.com/tanaes/whopping_Voron_mods/tree/main/LEDs/Rainbow_Barf_Logo_LED) or a Neopixel Mini Button (NEO). (https://www.adafruit.com/product/4776) (generic buttons should also fit)

2x M3 heat set inserts, 4x M3x6 screw, 2 M3 hex nuts, RBL or NEO PCB.

The diffuser should be printed in a clear (transparent) filament, but is rendered opaque on this page for better visuals. The diffuser holder / logo insert and carrier boards should be printed in black. The bed front should be printed in you accent color.

MapleLeafMakers Stealth Bed Front repository (https://github.com/MapleLeafMakers/Stealth_Bed_Front)

### Diffuser holder / Logo insert

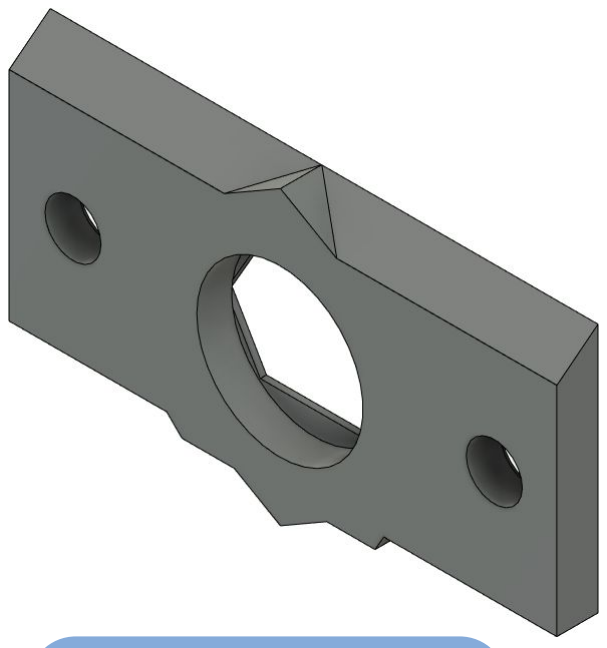
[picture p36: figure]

Diffuser front RBL/NEO | Carrier board NEO

### Carrier board RBL

### Diffuser rear NEO

### Diffuser rear RBL

PRINTED PARTS REFERENCE (OPTIONAL/MODS) | https://github.com/christophmuellerorg/voron_0_kirigami_bed

OPTIONAL PARTS / MODS
These parts are not required for a functional bed, but improve the use or look of the bed.

BED SPACERS

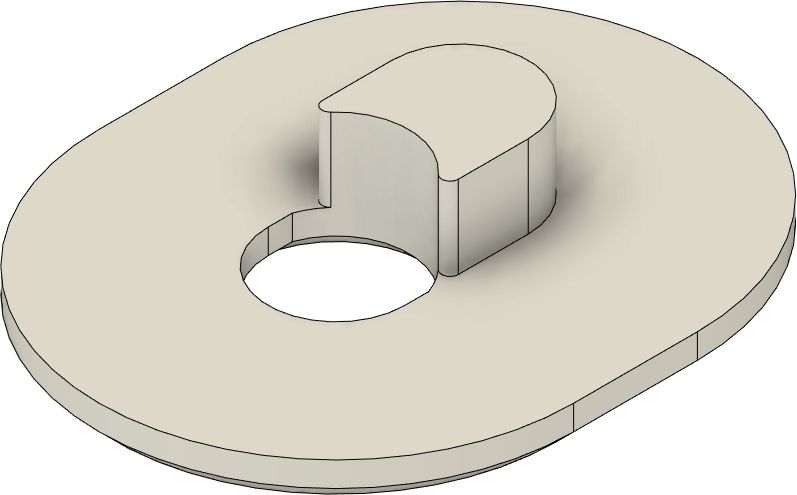
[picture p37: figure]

Steve Peterson/SteveBuilds has designed a set of bed spacers that can be used to align the bed screws to the from or rear of the slots in the Kirigami frame.

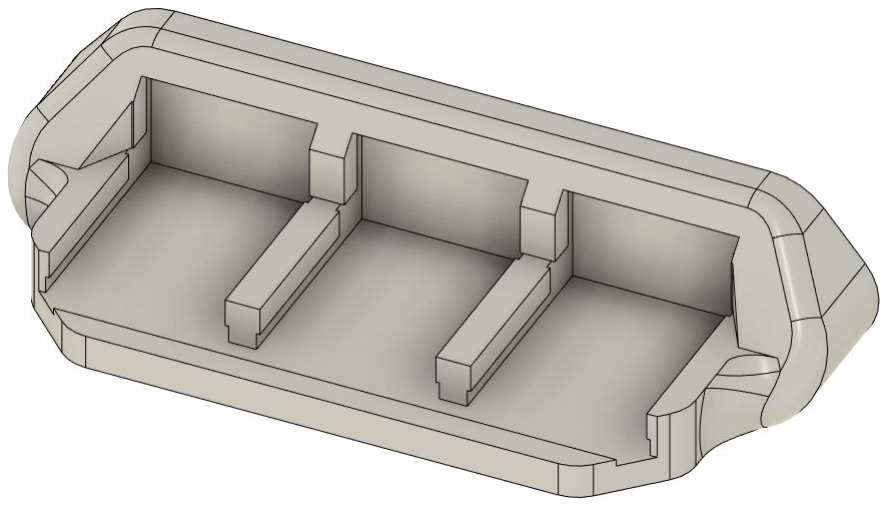
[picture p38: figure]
Kirigami_wago_mount.stl

You will want three of these, one for each slot.

You want to print this part in your primary color. It is rendered grey/white on this page for better visuals.

Steve's bed spacer files (https://github.com/stvptrsn/Printer_Stuff/tree/main/Voron_0/Kirigami)

GENERIC WAGO MOUNT
This generic mount allows you to mount three WAGO splicing connectors on the inside of the Kirigami bed. This enables you to cut the bed wires for easier bed removal.
2x M3 heat set inserts, 2x M3x6 screw.

You probably want to print this part in your primary color. It is rendered grey/white on this page for better visuals.

PART PREPARATION - HEATSET INSERTS | https://github.com/christophmuellerorg/voron_0_kirigami_bed

HEAT SET INSERTS
The printed parts for the Kirigami bed all need heat set inserts.

All the required and optional parts use the Voron standard heat set insert with M3 internal threads, a 5mm outer diameter and a height of 4mm.

It is generally recommended to heat your soldering iron to the approximate printing temperature of the printed part you are inserting the heat set inserts into.

The following pages have illustration for all required and optional parts. Simply skip any parts you are not using for on your build

HEAT SET INSERTS???
If you have never worked with heat set inserts before, your are recommend to watch a guide. The following guide from BV3D is the best guide we have found on the topic for far. https://www.youtube.com/watch?v=hwq15qH-4x4

HEAT SET SOLDERING TIPS (NO TRICKS)
While you can insert heat set inserts with a blunt tip on your soldering iron, it will go a lot easier if you purchase a tip specifically for heated inserts.

Our recommendations are either a tip set from CNCKitchen, or LDOs adjustable tip for M3 inserts. Also be aware that your heated inserts or printer build may already come with a heated insert tip.

CNCKitchen has tip sets for multiple types of soldering irons and insert diameters.
https://cnckitchen.store/collections/soldering-tips-and-sets

The LDO insert tool allows you to adjust the length of the tip according to the height of the insert to be used, but only fits M3 heated inserts, and requires a soldering iron compatible with 900M-T soldering tips. Compatible designs are however used in many soldering irons.
https://docs.ldomotors.com/guides/heatset_insert_tool_guide)

PART PREPARATION - HEATSET INSERTS | https://github.com/christophmuellerorg/voron_0_kirigami_bed

NUT BLOCK FOR V0.2 / V0.2R1
Be careful when working on the bottom two holes. The walls are intentionally made thin for backwards compatibility with V0.0.

NUT BLOCK FOR V0.0 / V0.1
Be careful when working on the bottom two holes. The walls are intentionally made thin for backwards compatibility with V0.0.

You may also insert the screw for the Z-endstop.

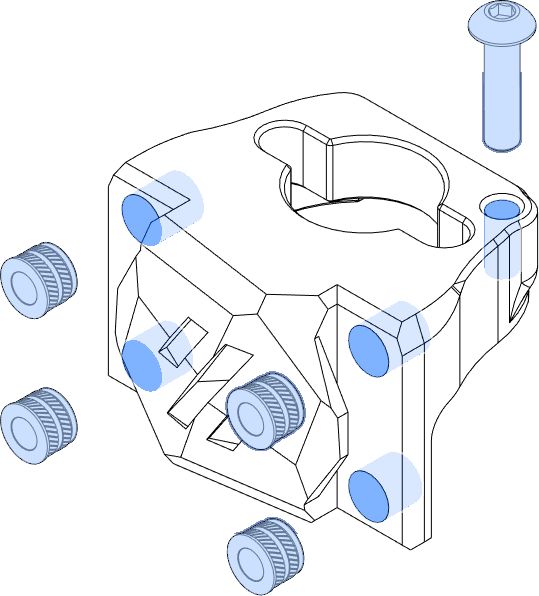
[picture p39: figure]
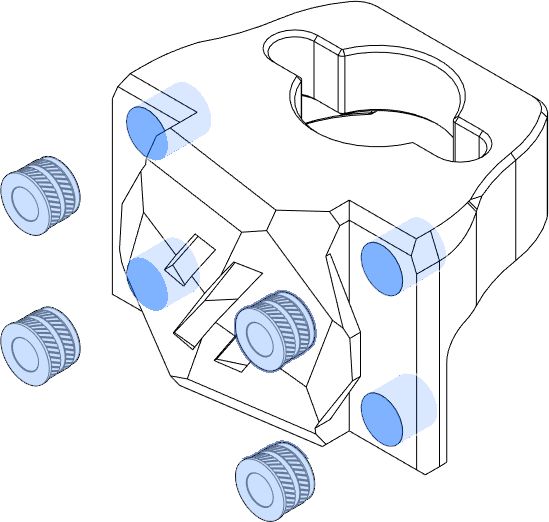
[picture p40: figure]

PART PREPARATION - HEATSET INSERTS | https://github.com/christophmuellerorg/voron_0_kirigami_bed
CHAIN MOUNT BLOCK FOR V0.2 / V0.2 R1 | WIRE GUIDE FOR V0.2 / V0.2 R1 / V0.1 with belt chain / V0.0 with belt chain Insert the heated insert from the closed side of the wire guide.

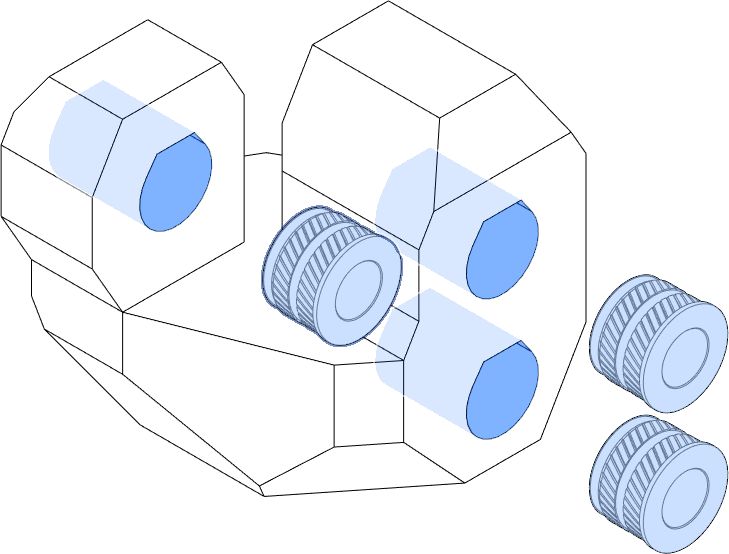
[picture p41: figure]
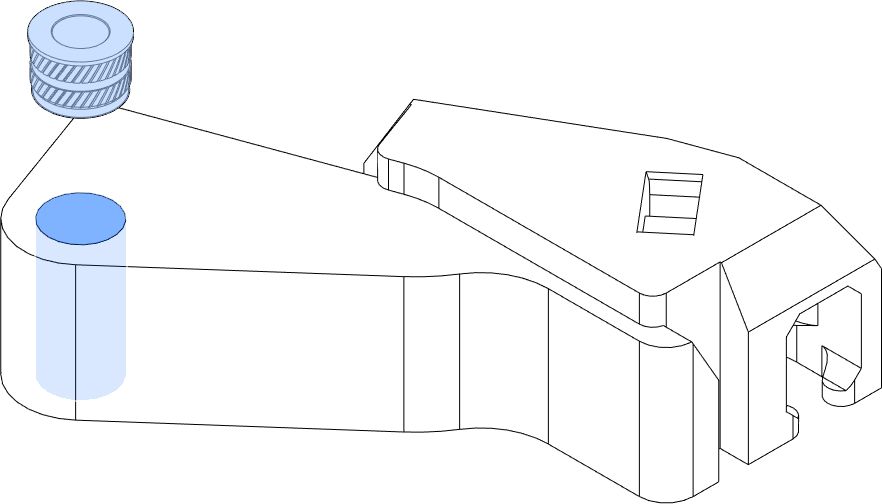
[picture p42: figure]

PART PREPARATION - HEATSET INSERTS | https://github.com/christophmuellerorg/voron_0_kirigami_bed

## https://github.com/christophmuellerorg/voron_0_kirigami_bed

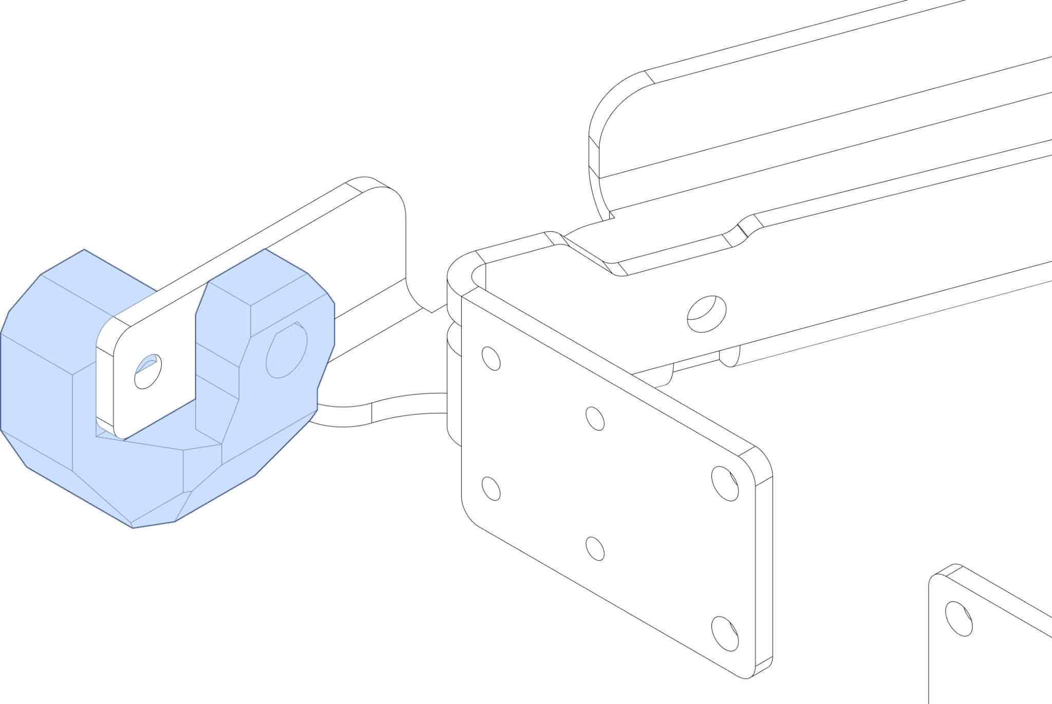
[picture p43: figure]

Bed spacers:
Yea, nozzle position for 0.0 and 0.2 is the same. 0.1 was forward (screws forward)

LDO WIRING | https://github.com/christophmuellerorg/voron_0_kirigami_bed

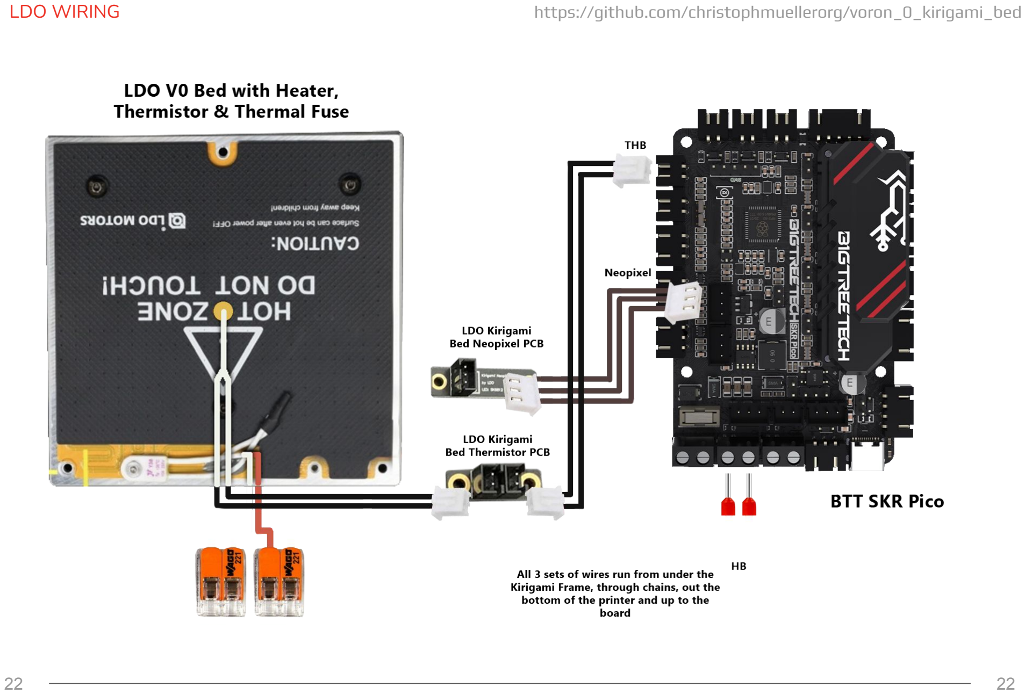
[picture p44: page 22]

RANDOM WIP NOTES | https://github.com/christophmuellerorg/voron_0_kirigami_bed

https://github.com/VoronDesign/Voron-0/issues/302

https://blog.knottsco.com/blog/wagos-top-20-asked-questions-about-cage-cla mp-connection-system-pt.-1 (https://blog.knottsco.com/blog/wagos-top-20-asked-questions-about-cage-clamp-connection-system-pt.-1)

v0.2R1:
page 58 insert bottom plate.
page 107-112 z lead screw construction and mouting

v0.2:
page 58 insert bottom plate.
page 104-106 z lead screw construction and mouting

v0.1:
page 36 insert bottom plate.
page 59-64 z lead screw construction and mouting

v0.0:
page insert bottom plate.
page z lead screw construction and mouting

ADDITIONAL NOTES | https://github.com/christophmuellerorg/voron_0_kirigami_bed

24

REMEMBER
Wash your hands after using the toilet.

24

ALSO REMEMBER
The banana in the Voron V0.2 CAD is not for human consumption.

HOW WAS THIS MANUAL MADE | https://github.com/christophmuellerorg/voron_0_kirigami_bed

CADS https://github.com/christophmuellerorg/voron_0_kirigami_bed (bed) https://github.com/MotorDynamicsLab/LDOVoron0 (bed front) https://github.com/MapleLeafMakers/Stealth_Bed_Front (bed front) https://github.com/VoronDesign/Voron-0 (nuts, bolts, linear rails) https://mods.vorondesign.com/detail/F5KwWIjcSXwIeghsMo3A (Belt chain parts) https://github.com/Kagee/random-cads (WAGO, LDO PCBs, Zip ties)

### IMAGES

Images (Dropbox shared folder) (https://www.dropbox.com/sh/xdzj37tecdrwvar/AACf2TmKs_vlAFT9BN7JOuHsa?dl=0) used in this manual. Most are taken using “Capture image...” from Design view in Fusion, and then cropped.

### https://github.com/Kagee/kirigami-bed-manual

### TOOLS Autodesk Fusion 360 (Shaded and wireframe images) GIMP (editing and joining of images)

Imagemagick (for automatic cropping of images) - Link (Github Gist) (https://gist.github.com/Kagee/bf2a226dd93ce9f606c6e7832fe188e3) Google Slides (yes, really) - Link (Google Slides Template) (https://docs.google.com/presentation/d/1pmqJNl_5oPr7llVEg32YjIzOz8KS_hGxE1-wYMvLugQ/edit#slide=id.p)

## https://github.com/christophmuellerorg/voron_0_kirigami_bed KIRIGAMI

GITHUB
https://github.com/christophmuellerorg/voron_0_kirigami_bed

### KIRIGAMI ASSEMBLY MANUAL

The Kirigami bed was designed by Christoph Mueller.

### This manual was constructed by Kag_ee (Voron Discord) based on various CAD models and a Voron Manual template supplied by kyleisah (Voron Discord) and hartk#1213 (Voron Discord)

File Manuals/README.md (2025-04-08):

# Formbot 3D Voron 0.2r1 Kit Manual
## Using the Voron Design manual as a baseline
| Page | Description |
| --- | --- |
| 1-35 | Business as normal. These pages are fine as is. |
| 36-39 | Ignore these pages. Refer to the Kirigami manual.  |

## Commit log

2025-04-02 0.0
    Initial Upload
    [A_Drive_Frame_Lower_x1.stl, A_Drive_Frame_Upper_x1.stl, A_Idler_Lower_x1.stl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]
2025-04-06 0.1
    add'd umbilical
    [FramePCBCover.STL, PCB_Cover.step, PCB_Cover_Voron.stl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]
